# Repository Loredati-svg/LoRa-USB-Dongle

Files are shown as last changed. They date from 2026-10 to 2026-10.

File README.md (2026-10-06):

# LoRa USB Dongle

USB-C LoRa dongle for the 868 MHz band. It plugs into a PC and shows up as a serial port, with an SMA connector for the antenna.

## Hardware
- USB-C receptacle + USBLC6-2SC6 ESD protection
- VBUS polyfuse + AP2112K-3.3 LDO
- CP2102N USB-UART bridge
- STM32WLE5CCUx (LDO only, no SMPS), 32 MHz crystal, SWD header, reset button, status LEDs
- RF chain based on ST's STDES-WL5U2ILH: BALFHB-WL-06D3 IPD + BGS12WN6 RF switch + SMA jack

## Status
Schematic done (ERC clean). PCB layout in progress.

## Tools
KiCad 10

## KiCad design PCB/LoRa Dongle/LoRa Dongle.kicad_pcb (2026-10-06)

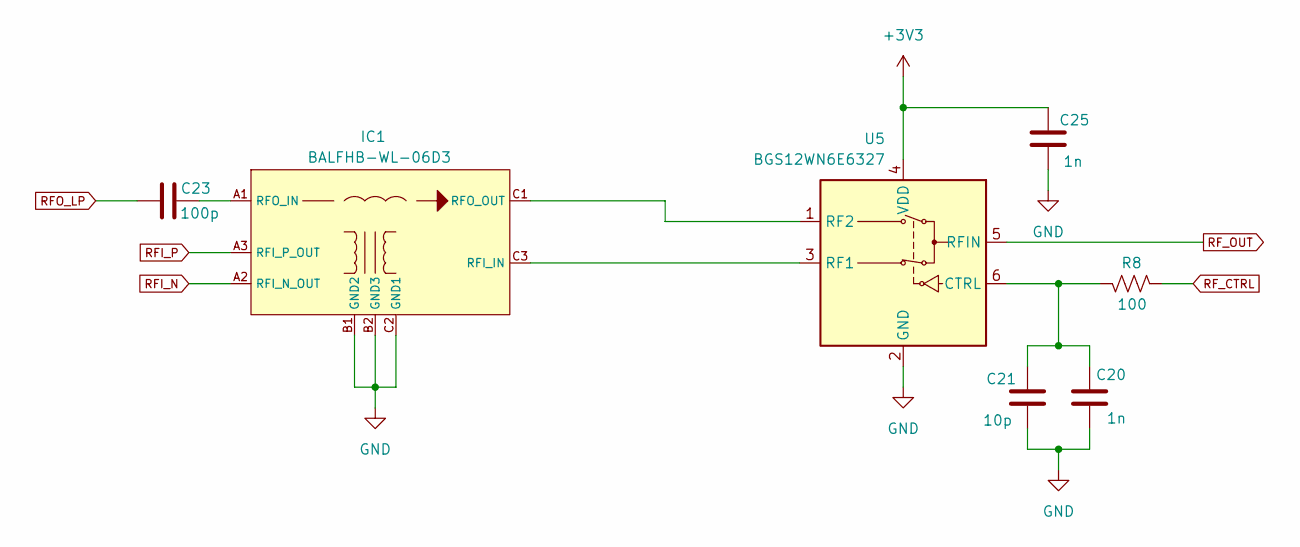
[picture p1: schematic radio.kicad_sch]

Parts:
C20, C25: 1n; C_0402
C21: 10p; C_0402
C23: 100p; C_0402
IC1: BALFHB-WL-06D3; BALFHBWL06D3
R8: 100; R_0402
U5: BGS12WN6E6327; Infineon_PG-TSNP-6-10_0.7x1.1mm_0.7x1.1mm_P0.4mm

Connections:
+3V3: C25.1, U5.4 (VDD); also elsewhere on the board
GND: C20.2, C21.2, C25.2, IC1.B1 (GND2), IC1.B2 (GND3), IC1.C2 (GND1), U5.2 (GND); also elsewhere on the board
unnamed: IC1.C3 (RFI_IN), U5.3 (RF1)
unnamed: C23.2, IC1.A1 (RFO_IN)
unnamed: IC1.C1 (RFO_OUT), U5.1 (RF2)
unnamed: C20.1, C21.1, R8.2, U5.6 (CTRL)
RFI_N: IC1.A2 (RFI_N_OUT); also elsewhere on the board
RFI_P: IC1.A3 (RFI_P_OUT); also elsewhere on the board
RFO_LP: C23.1; also elsewhere on the board
RF_CTRL: R8.1; also elsewhere on the board
RF_OUT: U5.5 (RFIN); also elsewhere on the board

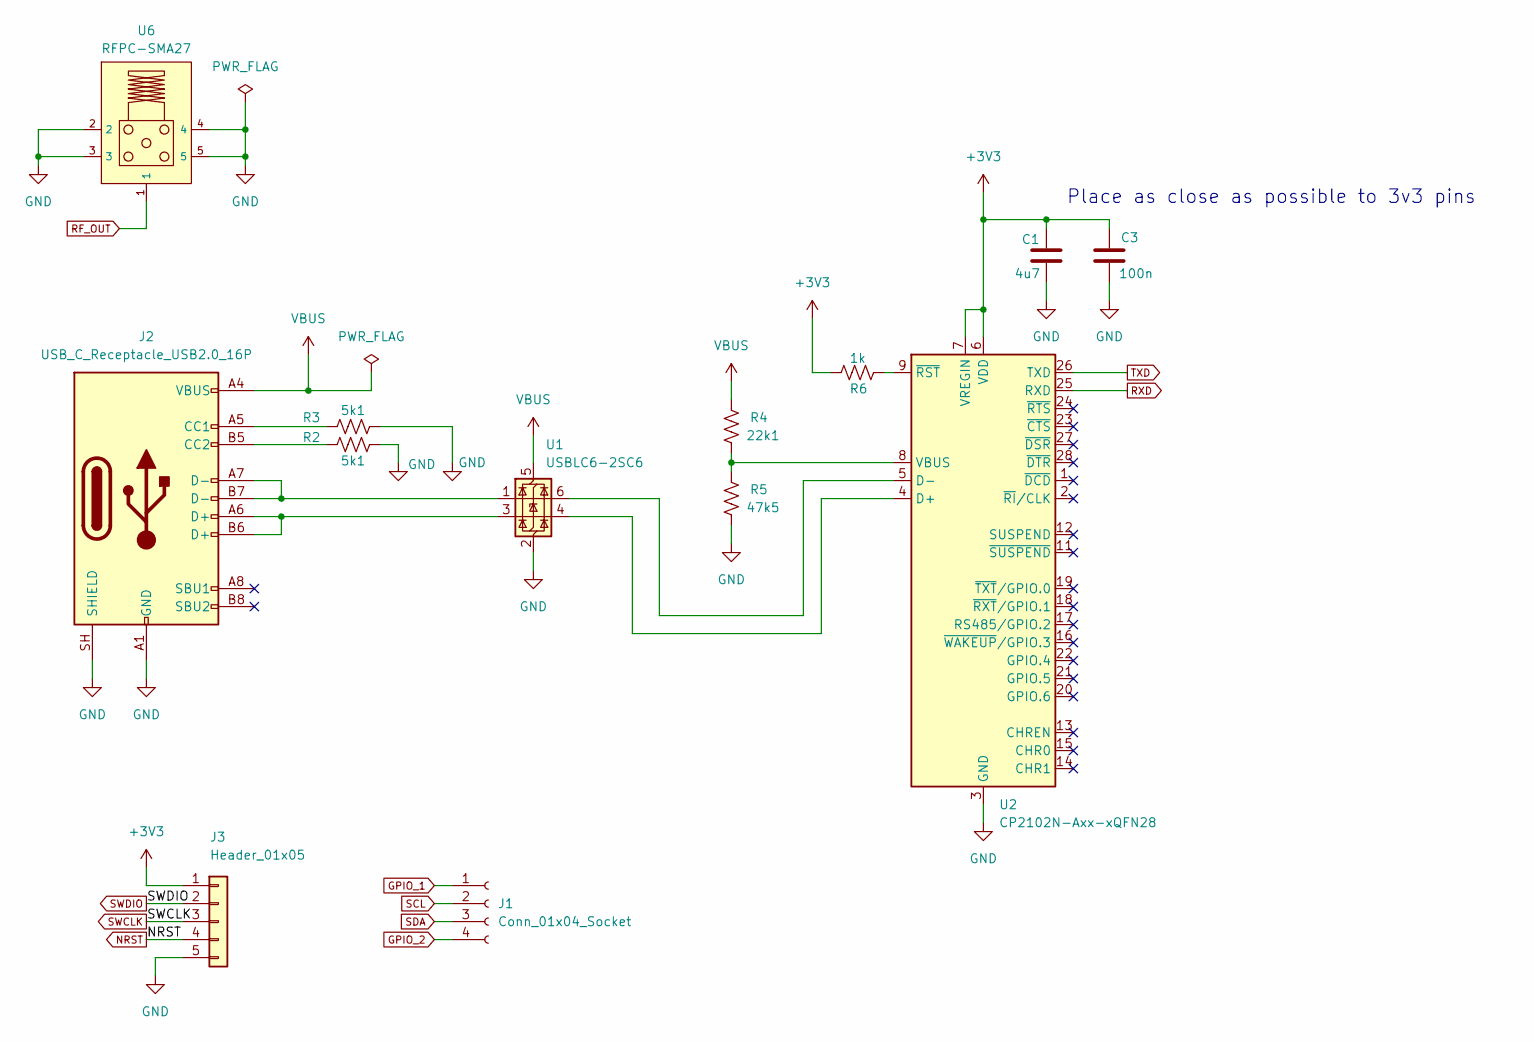
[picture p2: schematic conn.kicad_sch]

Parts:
C1: 4u7; C_0402
C3: 100n; C_0402
J1: Conn_01x04_Socket; PinHeader_1x04_P1.00mm_Vertical
J2: USB_C_Receptacle_USB2.0_16P; USB_C_Receptacle_GCT_USB4105-xx-A_16P_TopMnt_Horizontal
J3: Header_01x05; PinHeader_1x05_P1.00mm_Horizontal
R2, R3: 5k1; R_0402
R4: 22k1; R_0402
R5: 47k5; R_0402
R6: 1k; R_0402
U1: USBLC6-2SC6; SOT-23-6
U2: CP2102N-Axx-xQFN28; QFN-28-1EP_5x5mm_P0.5mm_EP3.35x3.35mm
U6: RFPC-SMA27; RFPCSMA27F

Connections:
+3V3: C1.1, C3.1, J3.1, R6.1, U2.6 (VDD), U2.7 (VREGIN); also elsewhere on the board
GND: C1.2, C3.2, J2.A1 (GND), J2.A12 (GND), J2.B1 (GND), J2.B12 (GND), J2.SH (SHIELD), J3.5, R2.2, R3.2, R5.2, U1.2 (GND), U2.3 (GND), U2.29 (GND), U6.2, U6.3, U6.4, U6.5; also elsewhere on the board
GPIO_1: J1.1; also elsewhere on the board
GPIO_2: J1.4; also elsewhere on the board
NRST: J3.4; also elsewhere on the board
unnamed: J2.A5 (CC1), R3.1
unnamed: J2.B5 (CC2), R2.1
unnamed: J2.A6 (D+), J2.B6 (D+), U1.3 (I/O2)
unnamed: J2.A7 (D-), J2.B7 (D-), U1.1 (I/O1)
unnamed: U1.4 (I/O2), U2.4 (D+)
unnamed: U1.6 (I/O1), U2.5 (D-)
unnamed: R4.2, R5.1, U2.8 (VBUS)
unnamed: R6.2, U2.9 (~RST)
RF_OUT: U6.1; also elsewhere on the board
RXD: U2.25 (RXD); also elsewhere on the board
SCL: J1.2; also elsewhere on the board
SDA: J1.3; also elsewhere on the board
SWCLK: J3.3; also elsewhere on the board
SWDIO: J3.2; also elsewhere on the board
TXD: U2.26 (TXD); also elsewhere on the board
VBUS: J2.A4 (VBUS), J2.A9 (VBUS), J2.B4 (VBUS), J2.B9 (VBUS), R4.1, U1.5 (VBUS); also elsewhere on the board

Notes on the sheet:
Place as close as possible to 3v3 pins

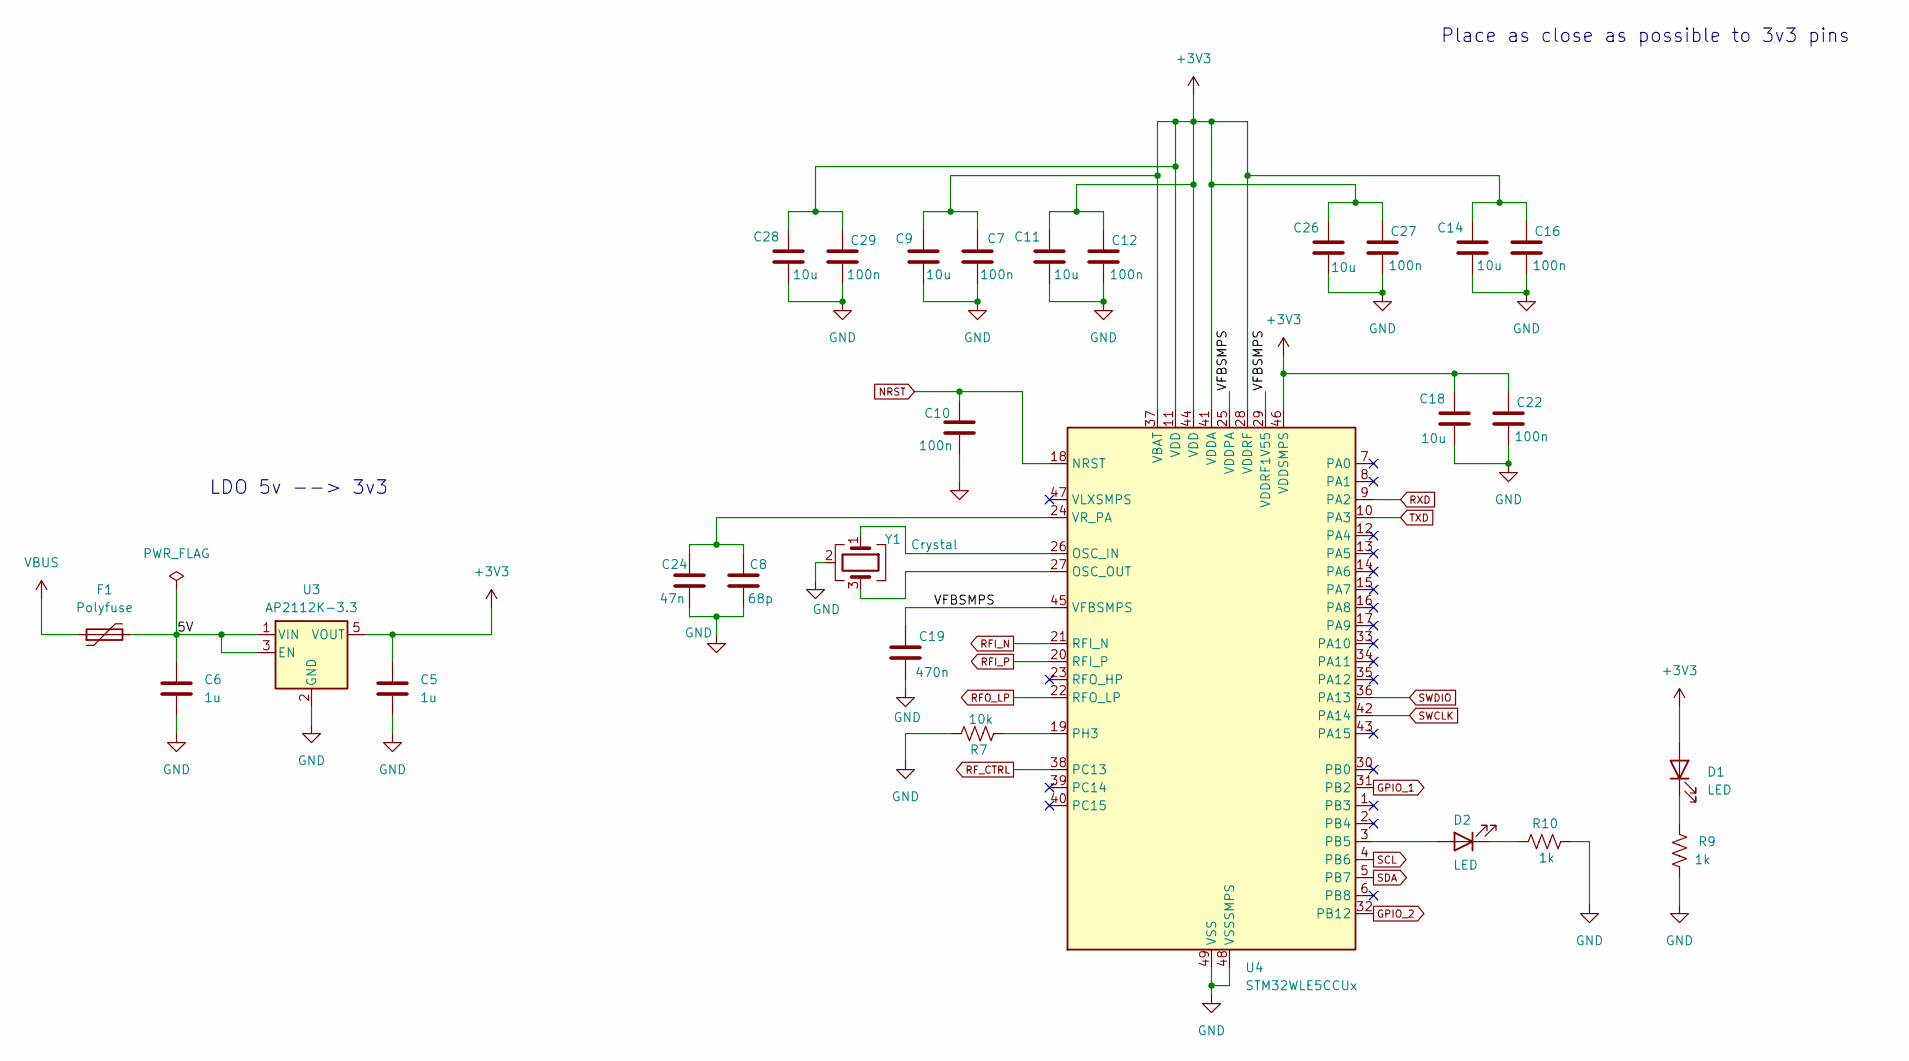
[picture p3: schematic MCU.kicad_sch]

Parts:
C5, C6: 1u; C_0402
C7, C10, C12, C16, C22, C27, C29: 100n; C_0402
C8: 68p; C_0402
C9, C11, C14, C18, C26, C28: 10u; C_0402
C19: 470n; C_0402
C24: 47n; C_0402
D1, D2: LED; LED_0603_1608Metric
F1: Polyfuse; Fuse_1210_3225Metric
R7: 10k; R_0402
R9, R10: 1k; R_0402
U3: AP2112K-3.3; SOT-23-5
U4: STM32WLE5CCUx; QFN-48-1EP_7x7mm_P0.5mm_EP5.6x5.6mm
Y1: Crystal; Crystal_SMD_2016-4Pin_2.0x1.6mm

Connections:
+3V3: C5.1, C7.1, C9.1, C11.1, C12.1, C14.1, C16.1, C18.1, C22.1, C26.1, C27.1, C28.1, C29.1, D1.2 (A), U3.5 (VOUT), U4.11 (VDD), U4.28 (VDDRF), U4.37 (VBAT), U4.41 (VDDA), U4.44 (VDD), U4.46 (VDDSMPS); also elsewhere on the board
/MCU/5V: C6.1, F1.2, U3.1 (VIN), U3.3 (EN)
/MCU/VFBSMPS: C19.1, U4.25 (VDDPA), U4.29 (VDDRF1V55), U4.45 (VFBSMPS)
GND: C5.2, C6.2, C7.2, C8.2, C9.2, C10.2, C11.2, C12.2, C14.2, C16.2, C18.2, C19.2, C22.2, C24.2, C26.2, C27.2, C28.2, C29.2, R7.1, R9.2, R10.2, U3.2 (GND), U4.48 (VSSSMPS), U4.49 (VSS), Y1.2 (G), Y1.4 (G); also elsewhere on the board
GPIO_1: U4.31 (PB2); also elsewhere on the board
GPIO_2: U4.32 (PB12); also elsewhere on the board
NRST: C10.1, U4.18 (NRST); also elsewhere on the board
unnamed: D1.1 (K), R9.1
unnamed: D2.2 (A), U4.3 (PB5)
unnamed: D2.1 (K), R10.1
unnamed: U4.26 (OSC_IN), Y1.1
unnamed: U4.27 (OSC_OUT), Y1.3
unnamed: R7.2, U4.19 (PH3)
unnamed: C8.1, C24.1, U4.24 (VR_PA)
RFI_N: U4.21 (RFI_N); also elsewhere on the board
RFI_P: U4.20 (RFI_P); also elsewhere on the board
RFO_LP: U4.22 (RFO_LP); also elsewhere on the board
RF_CTRL: U4.38 (PC13); also elsewhere on the board
RXD: U4.9 (PA2); also elsewhere on the board
SCL: U4.4 (PB6); also elsewhere on the board
SDA: U4.5 (PB7); also elsewhere on the board
SWCLK: U4.42 (PA14); also elsewhere on the board
SWDIO: U4.36 (PA13); also elsewhere on the board
TXD: U4.10 (PA3); also elsewhere on the board
VBUS: F1.1; also elsewhere on the board

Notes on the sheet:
LDO 5v --> 3v3
Place as close as possible to 3v3 pins

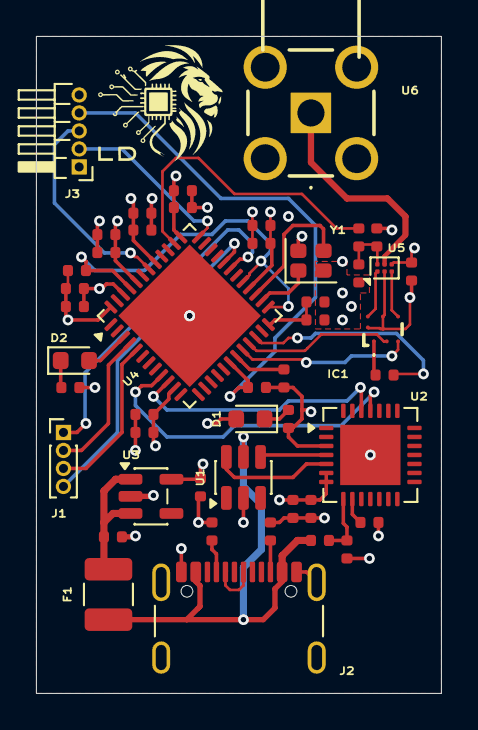
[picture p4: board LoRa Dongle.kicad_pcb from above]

Board: 4 copper layers, 22.5 x 36.5 mm, 47 parts (0 on the bottom side), 38 nets.

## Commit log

2026-10-06 Add KiCad project and libraries
    [LoRa Dongle.kicad_pcb, LoRa Dongle.kicad_sch, MCU.kicad_sch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]
2026-10-06 first layout
    [LoRa Dongle.kicad_pcb, MCU.kicad_sch, conn.kicad_sch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]
2026-10-13 Enhance README with detailed specifications and diagrams
    Expanded the README to include detailed specifications, block diagram, and RF chain information for the LoRa USB dongle.
2026-10-20 Use shared Kicad_Libs instead of project-specific libraries
    - Project parts moved to Kicad_Libs (symbol, footprint, 3D, datasheet)
    - Lib tables point to ${KIPRJMOD}/../KiCad_Libs (link via bring_libs.bat)
    - Schematic/PCB references (lib ids, footprints, 3D paths, datasheets)
    updated to the Kicad_Libs libraries; no design changes
    - Removed the old project-specific library folder
2026-10-22 Add library instructions to README
    Added instructions for cloning KiCad libraries and expected folder structure.
